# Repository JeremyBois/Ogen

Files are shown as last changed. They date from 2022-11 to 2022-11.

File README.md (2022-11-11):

# Ogen
A PMW3360 breakout board based on [this](https://www.tindie.com/products/jkicklighter/pmw3360-motion-sensor/).

Render
PCB
Schematic

 ## Changelog
 * 11/11/2022: Initial update to V1.2. This board is now ready for JLCPCB SMT assembly service:
   - Replace linear voltage regulator : from [TLV70019](https://jlcpcb.com/partdetail/TexasInstruments-TLV70019DDCR/C2862411) (out of stock) to [VRH1902LTX](https://jlcpcb.com/partdetail/Anasem-VRH1902LTX/C697975) (in stock)
   - Add metadata to each part to enable generation of BOM / POS using [this plugin](https://github.com/bennymeg/JLC-Plugin-for-KiCad)
 * 23/06/2022: Initial update to V1.1. Changed the 5 1-bit shift registers to 3 2-bit ones. Slightly shrunk board. New logo (very important).
 * 04/10/2020: Fixed major flaw in PMW3360 footprint.
 * 30/09/2020: Initial commit.

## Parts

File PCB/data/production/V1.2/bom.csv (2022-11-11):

Comment | Designator | Footprint | LCSC Part # | Quantity
4.7uF | C1 | C_0603_1608Metric | C19666 | 1
100nF | C2 | C_0603_1608Metric | C14663 | 1
1uF | C3, C4 | C_0603_1608Metric | C15849 | 2
10k | R1, R2 | R_0603_1608Metric | C25804 | 2
39R | R3 | R_0603_1608Metric | C227492 | 1
PMW3360DM-T2QU | U1 | IC_PMW3360DM-T2QU |  | 1
VRH1902LTX | U2 | SOT-23-5 | C697975 | 1
TXS0102DCU | U3, U4, U5 | VSSOP-8_2.3x2mm_P0.5mm | C53434 | 3

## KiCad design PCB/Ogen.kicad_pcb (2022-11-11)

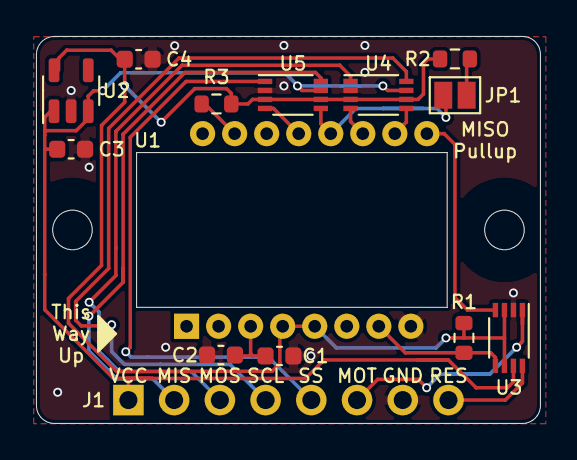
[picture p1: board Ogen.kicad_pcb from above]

Board: 2 copper layers, 28.0 x 21.5 mm, 17 parts (1 on the bottom side), 18 nets.

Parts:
A1: Art; Ariamelon_Logo
C1: 4.7uF; C_0603_1608Metric
C2: 100nF; C_0603_1608Metric
C3, C4: 1uF; C_0603_1608Metric
H1, H2: M2; MountingHole_2.2mm_M2
J1: Input; PinHeader_1x08_P2.54mm_Vertical
JP1: Jumper; SolderJumper-2_P1.3mm_Open_Pad1.0x1.5mm
R1, R2: 10k; R_0603_1608Metric
R3: 39R; R_0603_1608Metric
U1: PMW3360DM-T2QU; IC_PMW3360DM-T2QU
U2: VRH1902LTX; SOT-23-5
U3, U4, U5: TXS0102DCU; VSSOP-8_2.3x2mm_P0.5mm

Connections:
GND: C1.2, C2.2, C3.2, C4.2, J1.7, U1.8 (GND), U2.2 (GND), U3.2 (GND), U4.2 (GND), U5.2 (GND)
MISO: JP1.2 (B), U1.12 (MISO), U5.5 (A1)
MISO-H: J1.2, U5.8 (B1)
MOSI: U1.11 (MOSI), U4.4 (A2)
MOSI-H: J1.3, U4.1 (B2)
MOT: U1.9 (MOTION), U3.4 (A2)
MOT-H: J1.6, U3.1 (B2)
NRESET: R1.1, U1.7 (NRESET), U3.5 (A1)
NRESET-H: J1.8, U3.8 (B1)
unnamed: C1.1, C2.1, U1.3 (VDDPIX)
unnamed: JP1.1 (A), R2.1
unnamed: R3.1, U1.15 (LED_P)
SCLK: U1.10 (SCLK), U4.5 (A1)
SCLK-H: J1.4, U4.8 (B1)
SS: U1.13 (NCS), U5.4 (A2)
SS-H: J1.5, U5.1 (B2)
VCC: C3.1, J1.1, U2.1 (IN), U2.3 (EN), U3.7 (VCCB), U4.7 (VCCB), U5.7 (VCCB)
VDD: C4.1, R1.2, R2.2, R3.2, U1.4 (VDD), U1.5 (VDDIO), U2.5 (OUT), U3.3 (VCCA), U3.6 (OE), U4.3 (VCCA), U4.6 (OE), U5.3 (VCCA), U5.6 (OE)

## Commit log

2022-11-11 🚚 - Move V1.1 gerbers to corresponding folder.
2022-11-11 ✨ ♻️ - Add metadata required to generate BOM and POS files for JLCPCB SMT assembly service (can use Fabrication Toolkit plugin to generate up to date BOM and POS). Add description to PCB and schema f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
    [Ogen.kicad_pcb, Ogen.kicad_sch]
2022-11-11 🍱 - Add datasheet for both PMW3360DM sensor and Linear voltage regulator.
2022-11-11 🍱 - Generate production ready files for JLCPCB manufacturing and assembly.
    [bom.csv, designators.csv, positions.csv]
2022-11-11 📝 🍱 - Update schematic and bump to version V1.2. Update changelog accordingly.
2022-11-11 🙈 - Add gerber temp folder to gitignore.
